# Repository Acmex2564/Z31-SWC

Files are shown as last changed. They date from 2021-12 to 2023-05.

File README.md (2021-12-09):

# Z31-SWC

Reverse engineering of a 1986 Z31's optical steering wheel controls. 

The system consists of 3 components:
* The buttons & transmitter within the wheel
* The slip ring, optical ring, and head amplifier assembly ("clock spring") 
* The reciever, usually located behind the passenger seat

Only the first two subjects are documented here, since I don't have a reciever module. 

The transmitter module reads the values each of the 7 buttons & volume knob, and transmits the information via the slip ring assembly to the head amplifier. The head amplifier buffers the signal and signals to the reciever module, which then controls the radio and ASCD. 

The transmitter module is based on an NEC uPD652C 4-bit microcomputer. 1kbyte ROM, 32 word RAM. It reads & converts the buttons to 12-bit long serial strings, which flash an IR LED in the slip ring assembly. Bit widths are 1ms. 

As I capture them, the frames are laid out as follows:

0-11, from L->R

Resting State: 0101000XXXXX
* Bit 0    : Start of Frame, Always Low ("0" here)
* Bits 1-3 : Cruise Controls
* Bits 4-6 : Media Controls
* Bits 7-11: Volume Control

The actual buttons are:

Cruise Buttons (1-3):
* None	: 101
* Resume	: 011
* Accel	: 010
* Set		: 100

Media Buttons (4-6):
* None	: 000
* SW		: 001
* Tape	: 010
* FM/AM	: 100
* Scan	: 011

The head amplifier is based on an NEC uPC1251 op-amp and phototransistor. Output is made by pulling down the external data line to the reciever assembly. The reciever contains the pullup for this data line. 

The goal of this project is to replace the reciever assembly. The replacement reciever should be able to:
* Control the ASCD (4x 12V active high outputs), 
* Make all outputs available over CAN. 
* Maybe some other analog/resistive SWC outputs?

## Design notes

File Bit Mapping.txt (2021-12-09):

L->R, 0-11

Bit 0: Start
Bit 1:3: Cruise Controls
Bit 4:6: Media Controls
Bit 7:11: Volume Pot

Cruise Buttons:
None	: 101
Resume	: 011
Accel	: 010
Set		: 100

Media Buttons:
None	: 000
SW		: 001
Tape	: 010
FM/AM	: 100
Scan	: 011

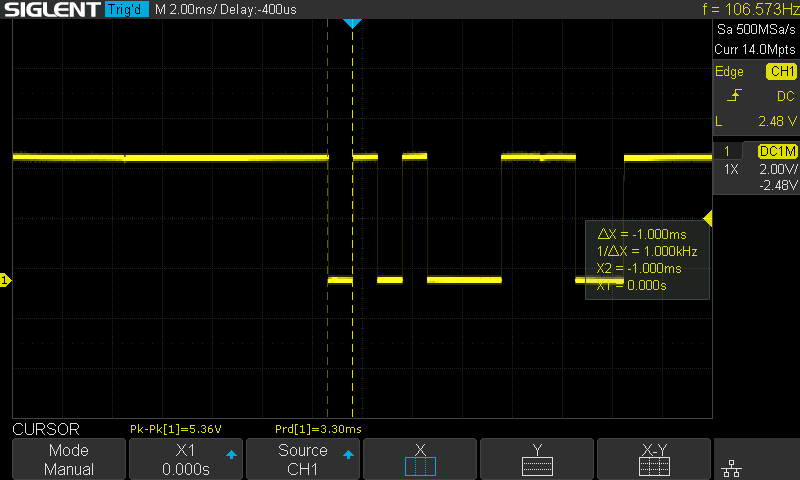
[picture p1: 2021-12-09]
Capture2.bmp

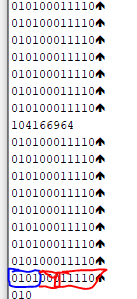
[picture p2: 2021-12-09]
Capture.PNG

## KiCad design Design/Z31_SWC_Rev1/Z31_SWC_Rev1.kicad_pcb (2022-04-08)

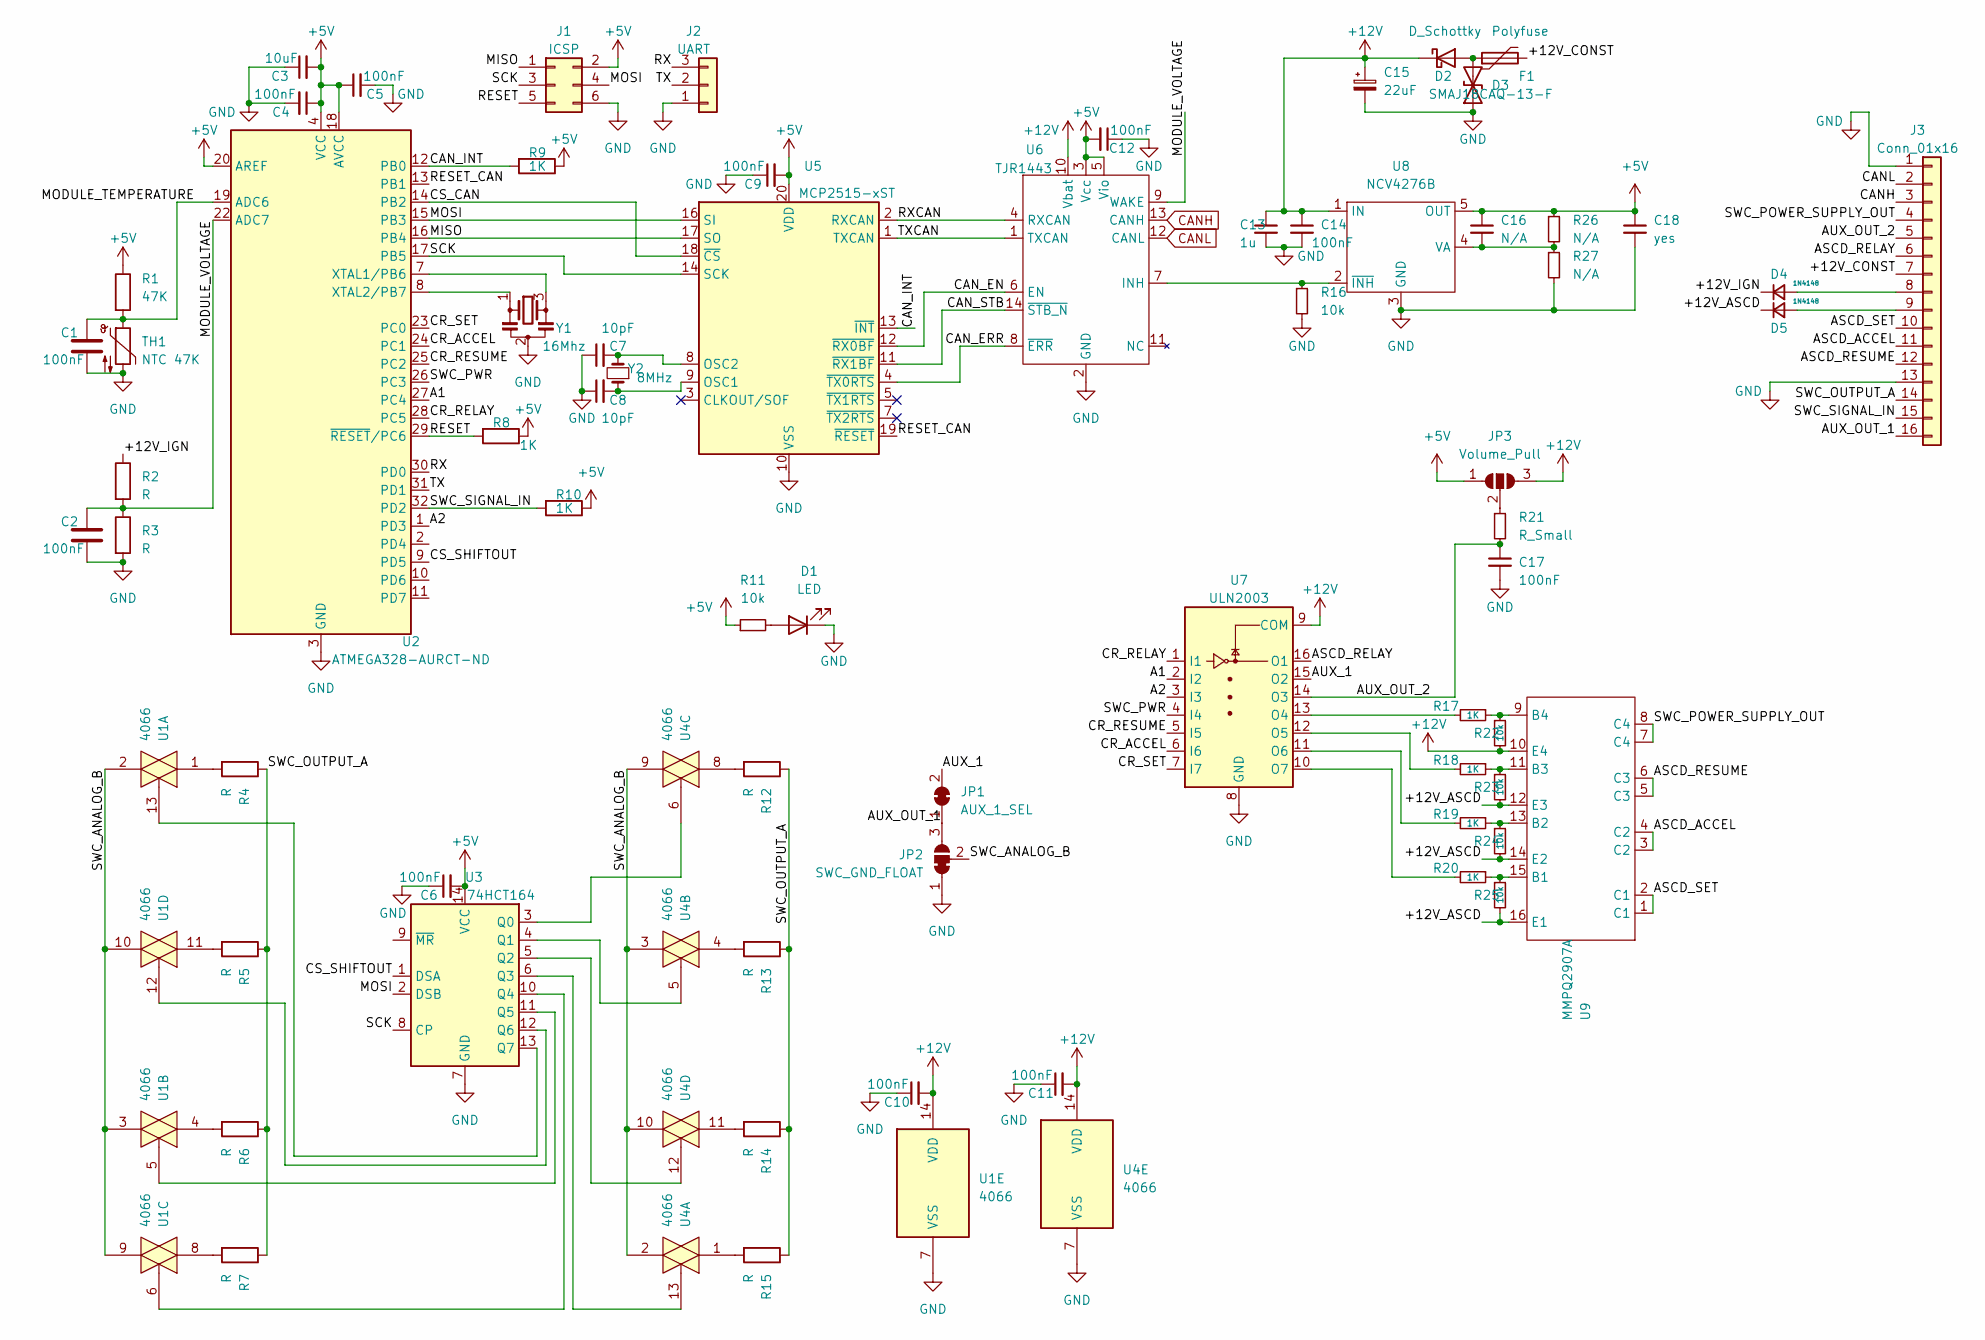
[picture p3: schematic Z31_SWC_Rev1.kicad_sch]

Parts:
C1, C2, C4, C5, C6, C9, C10, C11, C12, C14, C17: 100nF; C_0805_2012Metric_Pad1.18x1.45mm_HandSolder
C3: 10uF; CP_Elec_5x5.7
C7, C8: 10pF; C_0805_2012Metric_Pad1.18x1.45mm_HandSolder
C13: 1u; C_1210_3225Metric_Pad1.33x2.70mm_HandSolder
C15: 22uF; CP_Elec_5x5.7
C16: N/A; C_0805_2012Metric_Pad1.18x1.45mm_HandSolder
C18: yes; C_1210_3225Metric_Pad1.33x2.70mm_HandSolder
D1: LED; LED_0805_2012Metric
D2: D_Schottky; D_SMA
D3: SMAJ18CAQ-13-F; D_SMA
D4, D5: 1N4148; D_SOD-323_HandSoldering
F1: Polyfuse; Fuse_1812_4532Metric_Pad1.30x3.40mm_HandSolder
J1: ICSP; PinHeader_2x03_P2.54mm_Vertical
J2: UART; PinHeader_1x03_P2.54mm_Vertical
J3: Conn_01x16; 0348260160
JP1: AUX_1_SEL; SolderJumper-2_P1.3mm_Bridged_Pad1.0x1.5mm
JP2: SWC_GND_FLOAT; SolderJumper-3_P1.3mm_Bridged12_Pad1.0x1.5mm_NumberLabels
JP3: Volume_Pull; SolderJumper-3_P1.3mm_Open_RoundedPad1.0x1.5mm_NumberLabels
R1: 47K; R_0805_2012Metric_Pad1.20x1.40mm_HandSolder
R2, R3: R; R_0805_2012Metric_Pad1.20x1.40mm_HandSolder
R4, R5, R6, R7, R12, R13, R14, R15: R; R_Axial_DIN0207_L6.3mm_D2.5mm_P7.62mm_Horizontal
R8, R9, R10, R17, R18, R19, R20: 1K; R_0805_2012Metric_Pad1.20x1.40mm_HandSolder
R11, R16, R22, R23, R24, R25: 10k; R_0805_2012Metric_Pad1.20x1.40mm_HandSolder
R21: R_Small; R_0805_2012Metric_Pad1.20x1.40mm_HandSolder
R26, R27: N/A; R_0805_2012Metric_Pad1.20x1.40mm_HandSolder
TH1: NTC 47K; R_0805_2012Metric_Pad1.20x1.40mm_HandSolder
U1, U4: 4066; SOIC-14_3.9x8.7mm_P1.27mm
U2: ATMEGA328-AURCT-ND; TQFP-32_7x7mm_P0.8mm
U3: 74HCT164; SOIC-14_3.9x8.7mm_P1.27mm
U5: MCP2515-xST; TSSOP-20_4.4x6.5mm_P0.65mm
U6: TJR1443; SO-14_3.9x8.65mm_P1.27mm
U7: ULN2003; SOIC-16_3.9x9.9mm_P1.27mm
U8: NCV4276B; TO-263-5_TabPin3
U9: MMPQ2907A; SOIC-16_3.9x9.9mm_P1.27mm
Y1: 16Mhz; Resonator_SMD_Murata_CSTxExxV-3Pin_3.0x1.1mm_HandSoldering
Y2: 8MHz; Crystal_SMD_HC49-SD

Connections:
+5V: C3.2, C4.1, C5.1, C6.2, C9.2, C12.2, C16.1, C18.1, J1.2, JP3.1 (A), R1.1, R8.1, R9.1, R10.1, R11.1, R26.1, U2.4 (VCC), U2.6 (VCC), U2.18 (AVCC), U2.20 (AREF), U3.14 (VCC), U5.20 (VDD), U6.3 (Vcc), U6.5 (Vio), U8.5 (OUT)
+12V: C10.2, C11.2, C13.1, C14.1, C15.1, D2.1 (K), JP3.3 (B), R22.2, U1.14 (VDD), U4.14 (VDD), U6.10 (Vbat), U7.9 (COM), U8.1 (IN), U9.10 (E4)
/+12V_ASCD: D5.1 (K), R23.2, R24.2, R25.2, U9.12 (E3), U9.14 (E2), U9.16 (E1)
/+12V_CONST: F1.2, J3.7
/+12V_IGN: D4.1 (K), R2.1
/A1: U2.27 (PC4), U7.2 (I2)
/A2: U2.1 (PD3), U7.3 (I3)
/ASCD_ACCEL: J3.11, U9.3 (C2), U9.4 (C2)
/ASCD_RELAY: J3.6, U7.16 (O1)
/ASCD_RESUME: J3.12, U9.5 (C3), U9.6 (C3)
/ASCD_SET: J3.10, U9.1 (C1), U9.2 (C1)
/AUX_1: JP1.2 (B), U7.15 (O2)
/AUX_OUT_1: J3.16, JP1.1 (A), JP2.3 (B)
/AUX_OUT_2: C17.1, J3.5, R21.2, U7.14 (O3)
/CAN_EN: U5.12 (~RX0BF), U6.6 (EN)
/CAN_ERR: U5.4 (~TX0RTS), U6.8 (~ERR)
/CAN_INT: R9.2, U2.12 (PB0), U5.13 (~INT)
/CAN_STB: U5.11 (~RX1BF), U6.14 (~STB_N)
/CR_ACCEL: U2.24 (PC1), U7.6 (I6)
/CR_RELAY: U2.28 (PC5), U7.1 (I1)
/CR_RESUME: U2.25 (PC2), U7.5 (I5)
/CR_SET: U2.23 (PC0), U7.7 (I7)
/CS_CAN: U2.14 (PB2), U5.18 (~CS)
/CS_SHIFTOUT: U2.9 (PD5), U3.1 (DSA)
/MISO: J1.1, U2.16 (PB4), U5.17 (SO)
/MODULE_TEMPERATURE: C1.1, R1.2, TH1.1, U2.19 (ADC6)
/MODULE_VOLTAGE: C2.1, R2.2, R3.1, U2.22 (ADC7), U6.9 (WAKE)
/MOSI: J1.4, U2.15 (PB3), U3.2 (DSB), U5.16 (SI)
/RESET: J1.5, R8.2, U2.29 (~RESET/PC6)
/RESET_CAN: U2.13 (PB1), U5.19 (~RESET)
/RX: J2.3, U2.30 (PD0)
/RXCAN: U5.2 (RXCAN), U6.4 (RXCAN)
/SCK: J1.3, U2.17 (PB5), U3.8 (CP), U5.14 (SCK)
/SWC_ANALOG_B: JP2.2 (C), U1.2, U1.3, U1.9, U1.10, U4.2, U4.3, U4.9, U4.10
/SWC_OUTPUT_A: J3.14, R4.1, R5.1, R6.1, R7.1, R12.1, R13.1, R14.1, R15.1
/SWC_POWER_SUPPLY_OUT: J3.4, U9.7 (C4), U9.8 (C4)
/SWC_PWR: U2.26 (PC3), U7.4 (I4)
/SWC_SIGNAL_IN: J3.15, R10.2, U2.32 (PD2)
/TX: J2.2, U2.31 (PD1)
/TXCAN: U5.1 (TXCAN), U6.1 (TXCAN)
CANH: J3.3, U6.13 (CANH)
CANL: J3.2, U6.12 (CANL)
GND: C1.2, C2.2, C3.1, C4.2, C5.2, C6.1, C7.1, C8.1, C9.1, C10.1, C11.1, C12.1, C13.2, C14.2, C15.2, C17.2, C18.2, D1.1 (K), D3.1 (A1), J1.6, J2.1, J3.1, J3.13, JP2.1 (A), R3.2, R16.2, R27.2, TH1.2, U1.7 (VSS), U2.3 (GND), U2.5 (GND), U2.21 (GND), U3.7 (GND), U4.7 (VSS), U5.10 (VSS), U6.2 (GND), U7.8 (GND), U8.3 (GND), Y1.2
unnamed: C7.2, U5.8 (OSC2), Y2.2
unnamed: C8.2, U5.9 (OSC1), Y2.1
unnamed: C16.2, R26.2, R27.1, U8.4 (VA)
unnamed: D1.2 (A), R11.2
unnamed: D2.2 (A), D3.2 (A2), F1.1
unnamed: D4.2 (A), J3.8
unnamed: D5.2 (A), J3.9
unnamed: JP3.2 (C), R21.1
unnamed: R4.2, U1.1
unnamed: R5.2, U1.11
unnamed: R6.2, U1.4
unnamed: R7.2, U1.8
unnamed: R12.2, U4.8
unnamed: R13.2, U4.4
unnamed: R14.2, U4.11
unnamed: R15.2, U4.1
unnamed: R16.1, U6.7 (INH), U8.2 (~INH)
unnamed: R17.1, R22.1, U9.9 (B4)
unnamed: R17.2, U7.13 (O4)
unnamed: R18.1, R23.1, U9.11 (B3)
unnamed: R18.2, U7.12 (O5)
unnamed: R19.1, R24.1, U9.13 (B2)
unnamed: R19.2, U7.11 (O6)
unnamed: R20.1, R25.1, U9.15 (B1)
unnamed: R20.2, U7.10 (O7)
unnamed: U1.5, U3.11 (Q5)
unnamed: U1.6, U3.10 (Q4)
unnamed: U1.12, U3.12 (Q6)
unnamed: U1.13, U3.13 (Q7)
unnamed: U2.7 (XTAL1/PB6), Y1.3
unnamed: U2.8 (XTAL2/PB7), Y1.1
unnamed: U3.3 (Q0), U4.6
unnamed: U3.4 (Q1), U4.5
unnamed: U3.5 (Q2), U4.12
unnamed: U3.6 (Q3), U4.13

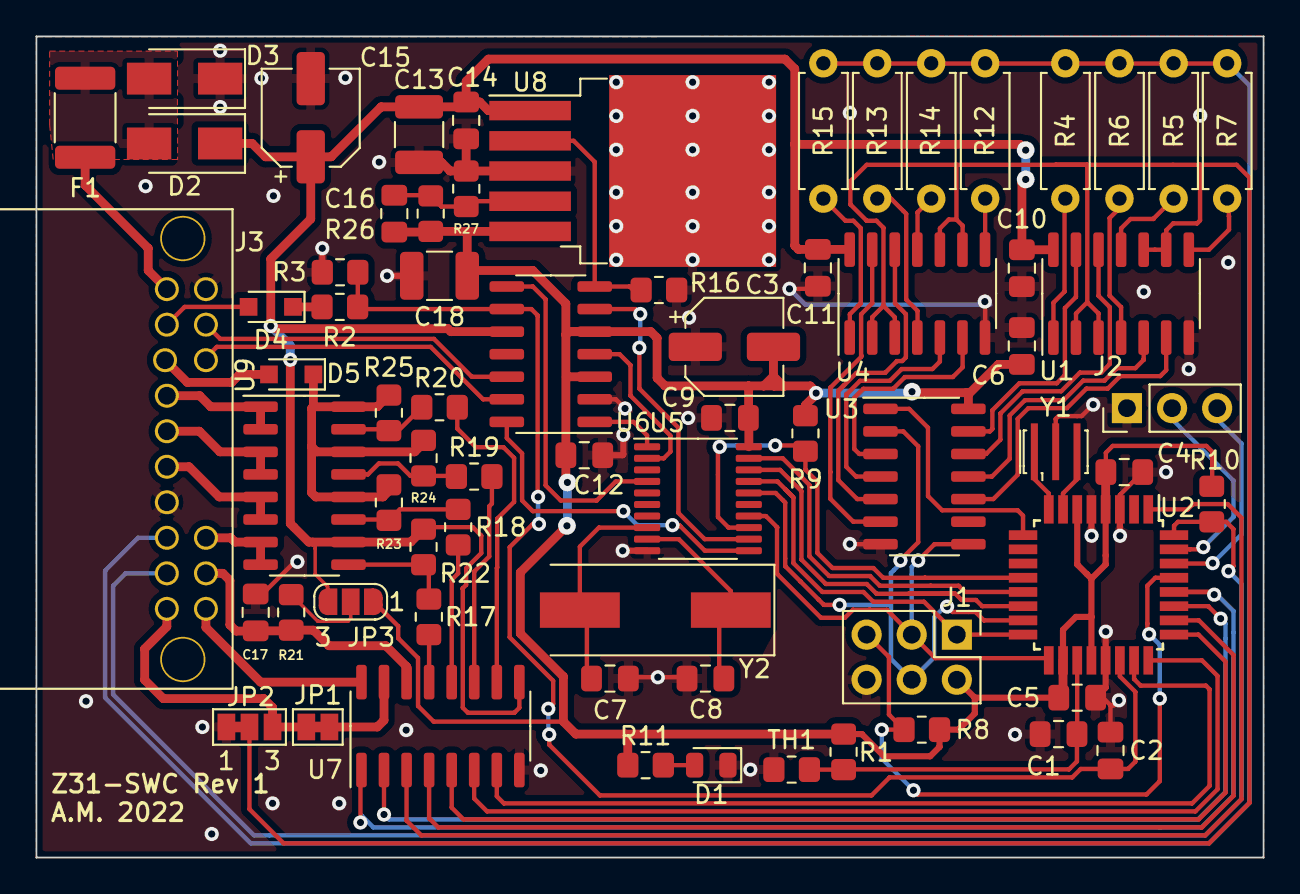
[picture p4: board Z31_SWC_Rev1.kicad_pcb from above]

Board: 2 copper layers, 69.1 x 46.2 mm, 69 parts (0 on the bottom side), 78 nets.

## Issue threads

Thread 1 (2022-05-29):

WAKE pin nonfunctional

Acmex2564, 2022-05-29:
Pin WAKE (MODULE_VOLTAGE) is pulled down by protection diode in ATMEGA, preventing module from waking on ignition terminal signal.

Add additional 200-300k resistor in series with ATMEGA pin to correct.

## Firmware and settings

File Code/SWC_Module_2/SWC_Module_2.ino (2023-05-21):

#include <mcp_can.h>
#include <SPI.h>
#include <avr/interrupt.h>
#include <avr/sleep.h>
#include <avr/wdt.h>

#define INPUT_PIN 2
//#define LED_PIN 13
#define BIT_TIME 1000 //microseconds
#define BIT_COUNT 12
#define TIMEOUT 15000 //microseconds
#define PRINT_PERIOD 1000000
#define HISTORY_COUNT 5

#define CAN_INT 8
#define CAN_CS 10

#define SHIFT_CS 5

#define MODULE_TEMP A6
#define MODULE_VOLTAGE A7

#define AUX_OUT_1 18
#define AUX_OUT_2 3 //pwm enabled
#define SWC_POWER 17
#define CRUISE_ACCEL 15 //L/Y --
#define CRUISE_SET 14 //L/OR
#define CRUISE_RESUME 16 //L/G
#define CRUISE_RELAY 19
#define CAN_RESET 9

#define BRIGHTNESS_ID 0x202
#define SWC_ID 0x1D6


volatile bool servicing = false;
int bitCounter = 0;
int serialData[12];
volatile long timeLastFall;
long timeCurrent;
unsigned long timeCurrent2;
long timeLastBit;
long timeLastPrint;
byte pinState;

const byte defaultCruise = 0b00000101;
byte stateCruise         = 0b00000101;

const byte defaultMedia  = 0b00000000;
byte stateMedia          = 0b00000000;

byte stateVolume         = 0b00000000;

bool stateValidButtons = false;

const uint32_t CAN_FREQ = 8000000; // 8 MHz
const uint32_t CAN_RATE = 500000; // 500 kbit/s
MCP_CAN CAN0(CAN_CS);
long unsigned int rxId;
unsigned char len = 0;
unsigned char rxBuf[8];
byte txBufSWC[3];
byte lastBufSWC[3];
char msgString[128];

int histCounter = 0;
int history[3][HISTORY_COUNT];

int histSum[3] = { defaultCruise * HISTORY_COUNT, defaultMedia * HISTORY_COUNT, 0} ;

const int interval_max_ign = 10 * 1000;
long timeLastIgn;
long timeLastCan;
boolean broadcast = false;

const int interval_swc_repeat = 500;
long timeLastSwc;

void setup() {
  // put your setup code here, to run once:
  pinMode(INPUT_PIN, INPUT);
  pinMode(CAN_INT, INPUT);
  pinMode(CAN_CS, OUTPUT);
  pinMode(CAN_RESET, OUTPUT);
  digitalWrite(CAN_RESET, LOW);
  pinMode(SHIFT_CS, OUTPUT);
  pinMode(AUX_OUT_1, OUTPUT);
  pinMode(AUX_OUT_2, OUTPUT);
  pinMode(SWC_POWER, OUTPUT);
  pinMode(CRUISE_ACCEL, OUTPUT);
  pinMode(CRUISE_SET, OUTPUT);
  pinMode(CRUISE_RESUME, OUTPUT);
  pinMode(CRUISE_RELAY, OUTPUT);


  Serial.begin(115200);
  Serial.println("Alive");


  for (int i = 0; i <= (HISTORY_COUNT - 1); i++) {
    history[0][i] = defaultCruise;
    history[1][i] = defaultMedia;
    history[2][i] = 0;
  }


  digitalWrite(CAN_RESET, HIGH);
  delay(10);

  if (CAN0.begin(MCP_ANY, CAN_500KBPS, MCP_8MHZ) == CAN_OK)
  {
    Serial.println("MCP2515 Initialized Successfully!");
  }
  else
  {
    Serial.println("Error Initializing MCP2515...");
  }
  CAN0.setMode(MCP_NORMAL);
  // set can transciever into normal mode
  CAN0.setGPO(0b00000011); //EN and STB HIGH

  attachInterrupt(digitalPinToInterrupt(INPUT_PIN), interrupt_svc, FALLING);
  digitalWrite(SWC_POWER, HIGH);

  wdt_enable(WDTO_8S);
  Serial.println("Awaiting SWC");
}

void loop() {
  // put your main code here, to run repeatedly:
  timeCurrent = micros();
  //Serial.println(((analogRead(MODULE_VOLTAGE)*5/1023.0 * ((35.7+90) / 35.7))));

  if (servicing) {

    if (timeCurrent - timeLastBit >= BIT_TIME) {
      //      digitalWrite(LED_PIN, HIGH);
      pinState = digitalRead(INPUT_PIN);
      //      digitalWrite(LED_PIN, LOW);
      if (pinState == HIGH) {
        serialData[bitCounter] = 1;
      }
      else {
        serialData[bitCounter] = 0;
      }
      bitCounter++;
      timeLastBit = timeCurrent;
    }

    //If the char has been filled, or if the timeout period has elapsed, reset to nothing
    if  ((bitCounter >= BIT_COUNT) || ((timeCurrent - timeLastFall) >= TIMEOUT)) {
      servicing = false;

      if (bitCounter == BIT_COUNT) {

        bitWrite(stateCruise, 2, serialData[1]);
        bitWrite(stateCruise, 1, serialData[2]);
        bitWrite(stateCruise, 0, serialData[3]);

        bitWrite(stateMedia, 2, serialData[4]);
        bitWrite(stateMedia, 1, serialData[5]);
        bitWrite(stateMedia, 0, serialData[6]);

        stateVolume = 0;

        bitWrite(stateVolume, 4, serialData[7]);
        bitWrite(stateVolume, 3, serialData[8]);
        bitWrite(stateVolume, 2, serialData[9]);
        bitWrite(stateVolume, 1, serialData[10]);
        bitWrite(stateVolume, 0, serialData[11]);

        stateVolume = map(stateVolume, 0, 32, 100, 0);

        stateValidButtons = true;
      }
      if ((timeCurrent - timeLastFall) >= TIMEOUT) {
        Serial.println("Timeout");
        stateCruise = defaultCruise;
        stateMedia = defaultMedia;
        stateValidButtons = true;
      }
      bitCounter = 0;
    }

  }

  //canbus shit goes here
  else {
    if ((analogRead(MODULE_VOLTAGE)*5/1023.0 * ((35.7+90) / 35.7)) > 10.0) {
      timeLastIgn = millis(); 
    }

    if (((millis() - timeLastIgn > interval_max_ign) && (millis() - timeLastCan > interval_max_ign )) || (millis() - timeLastIgn > 5 * interval_max_ign)) {
      poweroff();
    }

    if (millis() - timeLastIgn < interval_max_ign/2) {
      broadcast = true;
    }
    else {
      broadcast = false;
    }
      

    if (stateValidButtons) {

      histSum[0] = (histSum[0] - history[0][histCounter]) + stateCruise;
      history[0][histCounter] = stateCruise;
      histSum[1] = (histSum[1] - history[1][histCounter]) + stateMedia;
      history[1][histCounter] = stateMedia;
      histSum[2] = (histSum[2] - history[2][histCounter]) + stateVolume;
      history[2][histCounter] = stateVolume;
      //Serial.println(histCounter);
      //Serial.print(history[0][0]); Serial.print(history[0][1]); Serial.print(history[0][2]); Serial.print(history[0][3]); Serial.println(history[0][4]);
      //Serial.println(histSum[0]);
      if (histCounter >= (HISTORY_COUNT - 1))
      {
        histCounter = 0;
      }
      else
      {
        histCounter++;
      }

      if ((stateVolume == (histSum[2] / HISTORY_COUNT )) & (stateMedia == (histSum[1] / HISTORY_COUNT)) & (stateCruise == (histSum[0] / HISTORY_COUNT)))
      {
        txBufSWC[1] = stateMedia;
        txBufSWC[2] = stateVolume;
        txBufSWC[0] = stateCruise;
      }
      else
      {
        //Serial.println("History Mismatch.");
        //Serial.print(stateVolume); Serial.println(histSum[2] / HISTORY_COUNT);
        //Serial.print(stateMedia); Serial.println(histSum[1] / HISTORY_COUNT);
        //Serial.print(stateCruise); Serial.println(histSum[0] / HISTORY_COUNT);
        //Serial.println();

        txBufSWC[1] = defaultMedia;
        txBufSWC[2] = defaultCruise;
        stateCruise = defaultCruise;

      }


      if (((txBufSWC[0] != lastBufSWC[0]) || (txBufSWC[1] != lastBufSWC[1]) || (txBufSWC[2] != lastBufSWC[2]) || (millis() - timeLastSwc > interval_swc_repeat)) && broadcast)
      {
        if (CAN0.sendMsgBuf(SWC_ID, 0, 3, txBufSWC) == CAN_OK) {
          lastBufSWC[0] = txBufSWC[0];
          lastBufSWC[1] = txBufSWC[1];
          lastBufSWC[2] = txBufSWC[2];
          timeLastSwc = millis();
        }
        else {
          Serial.println("Tx SWC Failure");
          Serial.println(CAN0.sendMsgBuf(SWC_ID, 0, 3, txBufSWC));
        }
        
      }

      if (stateCruise == defaultCruise) {
        digitalWrite(CRUISE_ACCEL, LOW);
        digitalWrite(CRUISE_SET, LOW);
        digitalWrite(CRUISE_RESUME, LOW);
      }
      else if (stateCruise == 0b00000010) {
        digitalWrite(CRUISE_ACCEL, HIGH);
        digitalWrite(CRUISE_SET, LOW);
        digitalWrite(CRUISE_RESUME, LOW);
        Serial.println("Cruise Accel Pressed!");
      }
      else if (stateCruise == 0b00000011) {
        digitalWrite(CRUISE_ACCEL, LOW);
        digitalWrite(CRUISE_SET, LOW);
        digitalWrite(CRUISE_RESUME, HIGH);
        Serial.println("Cruise Resume Pressed!");
      }
      else if (stateCruise == 0b00000100) {
        digitalWrite(CRUISE_ACCEL, LOW);
        digitalWrite(CRUISE_SET, HIGH);
        digitalWrite(CRUISE_RESUME, LOW);
        Serial.println("Cruise Set Pressed!");
      }
      else {
        digitalWrite(CRUISE_ACCEL, LOW);
        digitalWrite(CRUISE_SET, LOW);
        digitalWrite(CRUISE_RESUME, LOW);
      }

      stateValidButtons = false;
    }

    //read for brightness message
    if (!digitalRead(CAN_INT))
    {
      CAN0.readMsgBuf(&rxId, &len, rxBuf);
      timeLastCan = millis();

      if (rxId == 0x202) {
        Serial.print("Recv'd brightness msg: ");

        for (byte i = 0; i < len; i++) {
          sprintf(msgString, "0x%.2x", rxBuf[i]);
          Serial.print(msgString);
        }
        Serial.println();
                
        if (rxBuf[0] == 0xFE) {
          analogWrite(AUX_OUT_2, 0xFF);
        }
        else {
          analogWrite(AUX_OUT_2, map(rxBuf[0], 0x0, 0xFD, 0xFF, 0x0));
        }

      }
    }
  }
wdt_reset();
}

void poweroff() {
  Serial.println("Poweroff");
  digitalWrite(SWC_POWER, LOW);
  CAN0.setGPO(0b00000001);
  delay(1000);
  //set_sleep_mode(SLEEP_MODE_PWR_DOWN);
  //cli();
  //sleep_mode();
}

void interrupt_svc() {

  servicing = true;
  timeLastFall = micros();
  delayMicroseconds(BIT_TIME / 2);
}

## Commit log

2022-04-08 Final Rev1 design
    [Z31_SWC_Rev1.kicad_pcb, Z31_SWC_Rev1.kicad_sch]
2023-05-21 Attemped SWC sleep/wake fix (module still slightly insomniac when battery voltage is low???)
    [SWC_Module_2.ino]
2023-05-21 Drop kicad_prl
